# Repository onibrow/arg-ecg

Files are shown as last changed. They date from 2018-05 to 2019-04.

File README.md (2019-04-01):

# Arias Research Group - BLE ECG

## References

### BLE

Task - Use the nRF52 Development Kit to send ECG data from the ADAS1000 over BLE to a phone to record data.

After careful assesment, I've decided to move forward with the Arduino BLEPeripheral library, after finding that someone has ported the SoftDevice functionality to Arduino IDE. This was mainly due to my unfamiliarity with the BLE stack, and the daunting, semeingly unknown and unfriendly Nordic toolchain.

To get it to work, I had to install a few packages:

```
libstdc++5
lib32-libstdc++5
libudev0-shim
gperf
lib32-attr
lib32-libcap
lib32-libgpg-error
libg32-libgcrypt
lib32-system
lib32-libudev0-shim
```

[nRF5 board files](https://github.com/sandeepmistry/arduino-nRF5)

[Arduino BLEPeripheral](https://github.com/sandeepmistry/arduino-BLEPeripheral)

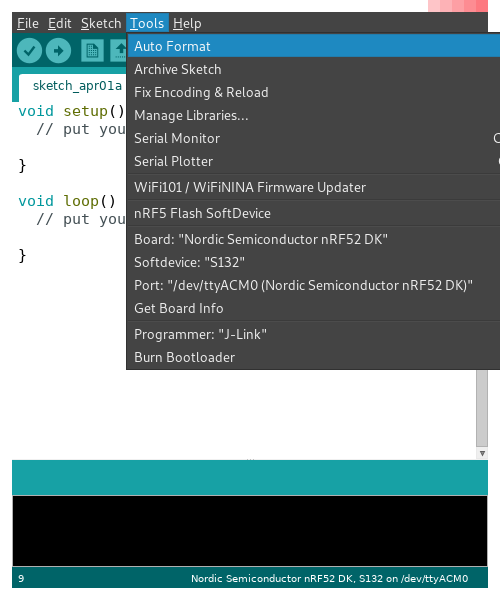
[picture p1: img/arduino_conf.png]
ard conf


### ADAS1000

[ADAS1000 Datasheet](https://www.analog.com/media/en/technical-documentation/data-sheets/ADAS1000_1000-1_1000-2.pdf)

[Eval Board Datasheet](http://www.analog.com/media/en/technical-documentation/user-guides/UG-426.pdf)

[Reference Design](https://www.analog.com/media/en/reference-design-documentation/reference-designs/CN0308.pdf)

There are two ADAS's on the eval board, one master one slave for a total of 12 electrode input. We'll utilize only 5 of them from the master chip using the pins LA, RA, LL, RLD, V1, V2. RLD (Right Leg Driver) can also be used as the common mode electrode. We can choose different electrode setups after we get the hardware to work by toggling what we want to use and get the optimal setup

SPI communication details

* Clock Polarity: Idle HIGH
* Clock Phase: Data is clocked into ADAS during the rising edges of SCLK, and shifted out (to be read) on falling edges of SCLK

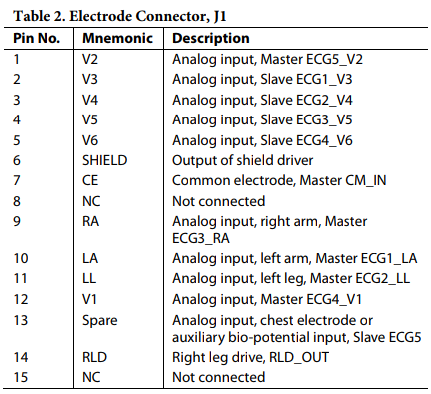
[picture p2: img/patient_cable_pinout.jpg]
patient


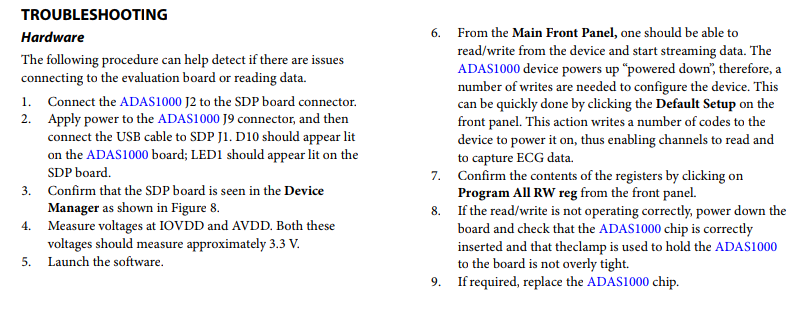
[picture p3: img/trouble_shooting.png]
trouble


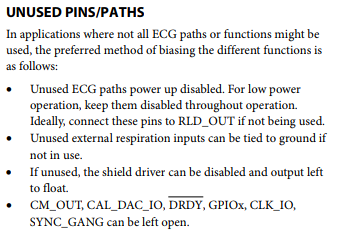
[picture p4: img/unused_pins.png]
unused


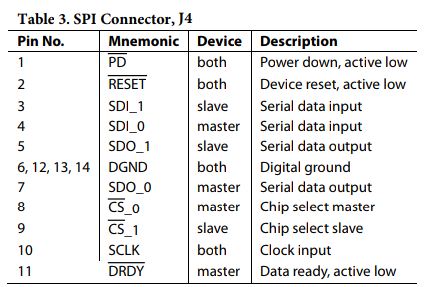
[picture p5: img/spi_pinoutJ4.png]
J4 SPI Out


[SPI Register Defs Page 60](https://www.analog.com/media/en/technical-documentation/data-sheets/ADAS1000_1000-1_1000-2.pdf)

### CC3200MOD\[DEPRACATED\] (WiFi)

[CC3200MOD Datasheet](http://www.ti.com/lit/ds/swrs166/swrs166.pdf)

[CC3200MOD LaunchPad User Guide](http://www.ti.com/lit/ug/swru397a/swru397a.pdf)

[CC3200MOD LaunchPad Schematic](http://www.ti.com/lit/df/tidrc48/tidrc48.pdf)

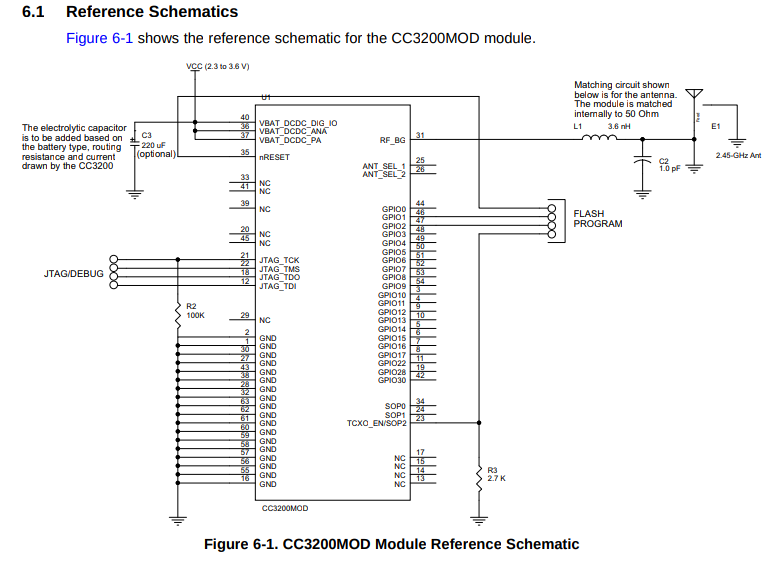
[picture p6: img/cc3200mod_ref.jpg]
CC3200MOD Refrence Schematic


[CC3200 Jumper Settings](http://energia.nu/guide/install/cc3200-guide/)

[CC3200 SPI <-> ADAS1000](https://ez.analog.com/linux-device-drivers/microcontroller-no-os-drivers/f/q-a/88100/adas-1000-to-arduino-code)

[More SPI stuff](https://www.element14.com/community/thread/46120/l/adas1000-interfacing-by-arduino-uno?displayFullThread=true)

## Other Wifi Modules

[ThingSpeak](https://thingspeak.com/)

[ESP8266](https://www.sparkfun.com/products/13678)

## IoT Server

Thinger.io is pretty nice - also has good integration with the launchpad - [Link](http://docs.thinger.io/arduino/#installation)

## Parts

All SMD components will be 0602 unless specified.

[8.192MHz](https://www.digikey.com/product-detail/en/citizen-finedevice-co-ltd/CM309S8.192MABJT/300-2039-1-ND/482155)

[1uH Inductor](https://www.digikey.com/product-detail/en/tdk-corporation/MLZ2012M1R0HT000/445-8657-1-ND/3077939)

[Chip Antenna](https://www.digikey.com/product-detail/en/taiyo-yuden/AH316M245001-T/587-2200-1-ND/2002898)

[DP3T](https://www.digikey.com/product-detail/en/c-k/JS203011JCQN/CKN10725CT-ND/6137639)

[2Pin JST](https://www.digikey.com/product-detail/en/jst-sales-america-inc/B2B-XH-A(LF)(SN)/455-2247-ND/1651045)

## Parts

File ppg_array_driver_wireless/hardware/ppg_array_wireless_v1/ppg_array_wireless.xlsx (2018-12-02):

Partli | st exported from C:/User | s/Yasser Khan/Dropbox/pr | oject_ppg_redundancy/ | ppg_array_driver_wireless/hardware/ppg_array_wireless_v1/ppg_array_wireless.sch at 10/5/2018 1:11 PM
Part | Value | Device | Package | Description PROD_ID
C1 | 1uF | CAP0603-CAP | 0603-CAP | Capacitor
C2 | 1uF | CAP0603-CAP | 0603-CAP | Capacitor
C3 | 18pF | CAP0603-CAP | 0603-CAP | Capacitor
C4 | 18pF | CAP0603-CAP | 0603-CAP | Capacitor
C5 | 2.2uF | CAP0603-CAP | 0603-CAP | Capacitor
C6 | 2.2uF | CAP0603-CAP | 0603-CAP | Capacitor
C7 | 1uF | CAP0603-CAP | 0603-CAP | Capacitor
C8 | 0.1uF | CAP0603-CAP | 0603-CAP | Capacitor
C9 | 1uF | CAP0603-CAP | 0603-CAP | Capacitor
C10 | 1uF | CAP0603-CAP | 0603-CAP | Capacitor
C11 | 1uF | CAP0603-CAP | 0603-CAP | Capacitor
C12 | 12pF | CAP0603-CAP | 0603-CAP | Capacitor
C13 | 12pF | CAP0603-CAP | 0603-CAP | Capacitor
C14 | 0.1uF | CAP0603-CAP | 0603-CAP | Capacitor
C15 | 0.1uF | CAP0603-CAP | 0603-CAP | Capacitor
C16 | 0.1uF | CAP0603-CAP | 0603-CAP | Capacitor
D1 | CZRU52C5V1 | CZRU52C5V1 | CZRU52C5V1
D2 | CZRU52C5V1 | CZRU52C5V1 | CZRU52C5V1
L1 | POWER | LEDCHIP-LED0603 | CHIP-LED0603 | LED
L2 | BLE | LEDCHIP-LED0603 | CHIP-LED0603 | LED
Q1 | ABRACON_ABM3_CRYSTAL | ABRACON_ABM3_CRYSTAL | ABRACON_ABM3_CRYSTAL
Q2 | FC-12M | FC-12M | FC-12M | kHz RANGE CRYSTAL UNIT
R1 | 1K | RESISTOR0603-RES | 0603-RES | Resistor
R2 | 1K | RESISTOR0603-RES | 0603-RES | Resistor
R3 | 10k | RESISTOR0603-RES | 0603-RES | Resistor
RESET |  | TAC_SWITCHSMD | TACTILE_SWITCH_SMD | SMD Tactiile Switch
S1 | AYZ0202 | AYZ0202 | AYZ0202 | SPDT Slide Switch SWCH-08179
U1 | MDBT40SMD | MDBT40SMD | MDBT40
U2 | AFE4490 | AFE4490 | QFN40-6X6
U3 | TESTING_ADXL335-PATRICK | TESTING_ADXL335-PATRICK | TESTING_LFCSP-16
U4 | ADG794 | ADG794 | QSOP16
U5 | MIC5211-LXYM6-TR | MIC5211-LXYM6-TR | SOT-23-6
X1 | 5034803200 | 5034803200 | 5034803200 | 0.5mm Pitch Connectors For FPC/FFC

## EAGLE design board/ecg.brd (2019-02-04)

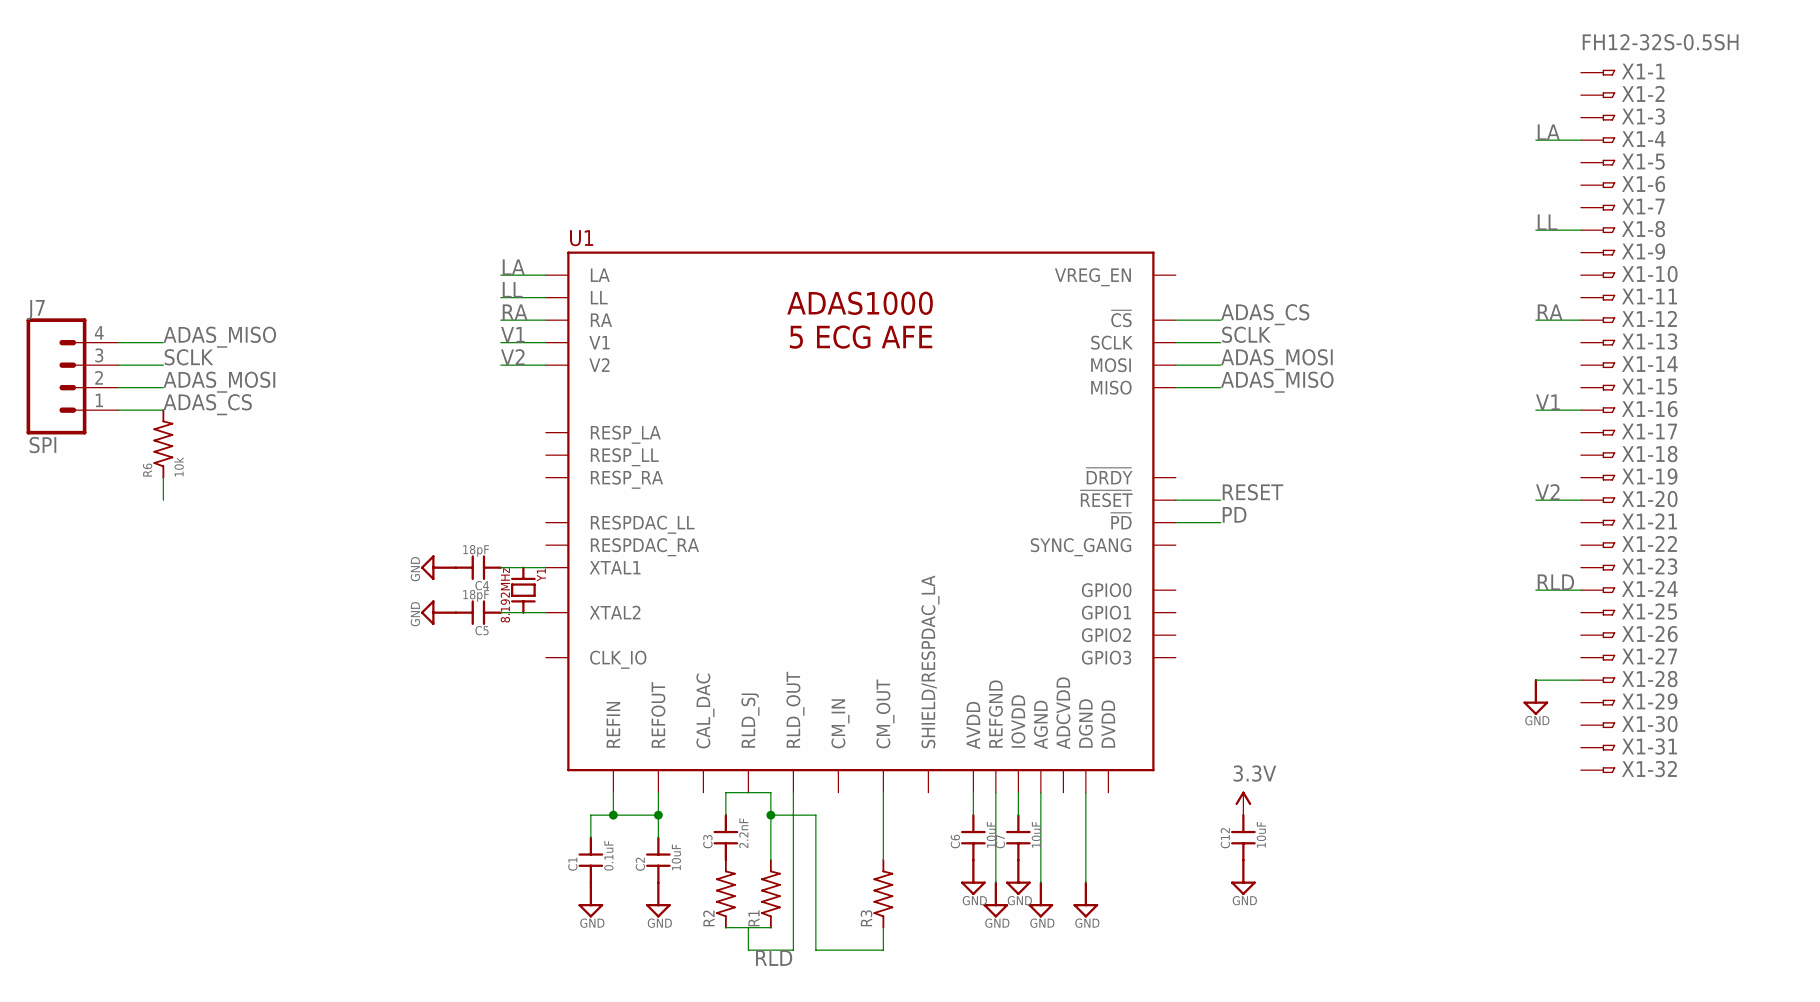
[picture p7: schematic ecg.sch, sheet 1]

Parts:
C1: 0.1uF; 0603-CAP
C2, C6, C7, C12: 10uF; 0603-CAP
C3: 2.2nF; 0603-CAP
C4, C5: 18pF; 0603-CAP
J7: SPI; 1X04
R1: 4M; R0603
R2: 100k; R0603
R3: 40k; R0603
R6: 10k; R0603
U1: ADAS1000; QFP50P1200X1200X160-65N
X1: FH12-32S-0.5SH
Y1: 8.192MHz; HC-49

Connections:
3.3V: C6.2, C7.2, C12.2, R6.1, U1.18 (AVDD), U1.23 (AVDD), U1.35 (IOVDD), U1.46 (IOVDD), U1.58 (AVDD), U1.63 (AVDD); also elsewhere on the board
ADAS_CS: J7.1, R6.2, U1.41 (!CS); also elsewhere on the board
ADAS_MISO: J7.4, U1.45 (MISO); also elsewhere on the board
ADAS_MOSI: J7.2, U1.43 (MOSI); also elsewhere on the board
GND: C1.1, C2.1, C4.2, C5.2, C6.1, C7.1, C12.1, U1.2 (AGND), U1.7 (REFGND), U1.15 (AGND), U1.24 (AGND), U1.25 (AGND), U1.31 (DGND), U1.34 (DGND), U1.40 (DGND), U1.47 (DGND), U1.50 (DGND), U1.56 (AGND), U1.57 (AGND), X1.28; also elsewhere on the board
LA: U1.10 (LA), X1.4
LL: U1.11 (LL), X1.8
unnamed: C1.2, C2.2, U1.8 (REFOUT), U1.9 (REFIN)
unnamed: C3.2, R1.2, R3.1, U1.21 (RLD_SJ)
unnamed: C3.1, R2.2
unnamed: R3.2, U1.22 (CM_OUT)
unnamed: C4.1, U1.27 (XTAL1), Y1.A
unnamed: C5.1, U1.28 (XTAL2), Y1.B
PD: U1.53 (!PD)
RA: U1.12 (RA), X1.12
RESET: U1.54 (!RESET)
RLD: R1.1, R2.1, U1.20 (RLD_OUT), X1.24
SCLK: J7.3, U1.44 (SCLK); also elsewhere on the board
V1: U1.13 (V1), X1.16
V2: U1.14 (V2), X1.20

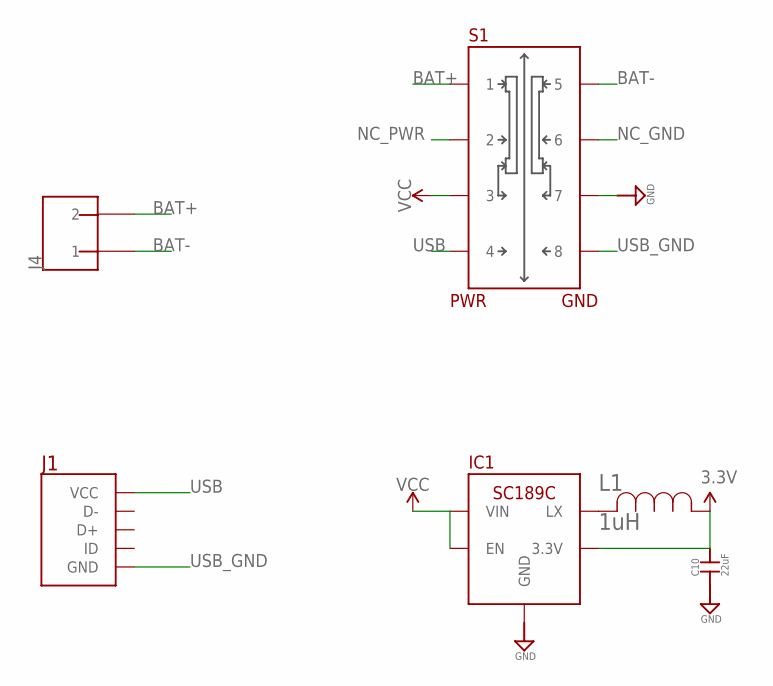
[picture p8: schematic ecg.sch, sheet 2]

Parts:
C10: 22uF; 0603-CAP
IC1: SC189C; SOT23-5
J1: USB_MICRO
J4: 2_PIN_JST-XH
L1: 1uH; IND_2012
S1: DP3T

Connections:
3.3V: C10.2, IC1.4 (3.3V), L1.1; also elsewhere on the board
BAT+: J4.P$2 (2), S1.1
BAT-: J4.P$1 (1), S1.5
GND: C10.1, IC1.2 (GND), S1.7; also elsewhere on the board
unnamed: IC1.5 (LX), L1.2
NC_GND: S1.6
NC_PWR: S1.2
USB: J1.VCC, S1.4
USB_GND: J1.GND, S1.8
VCC: IC1.1 (VIN), IC1.3 (EN), S1.3

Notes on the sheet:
PWR
GND

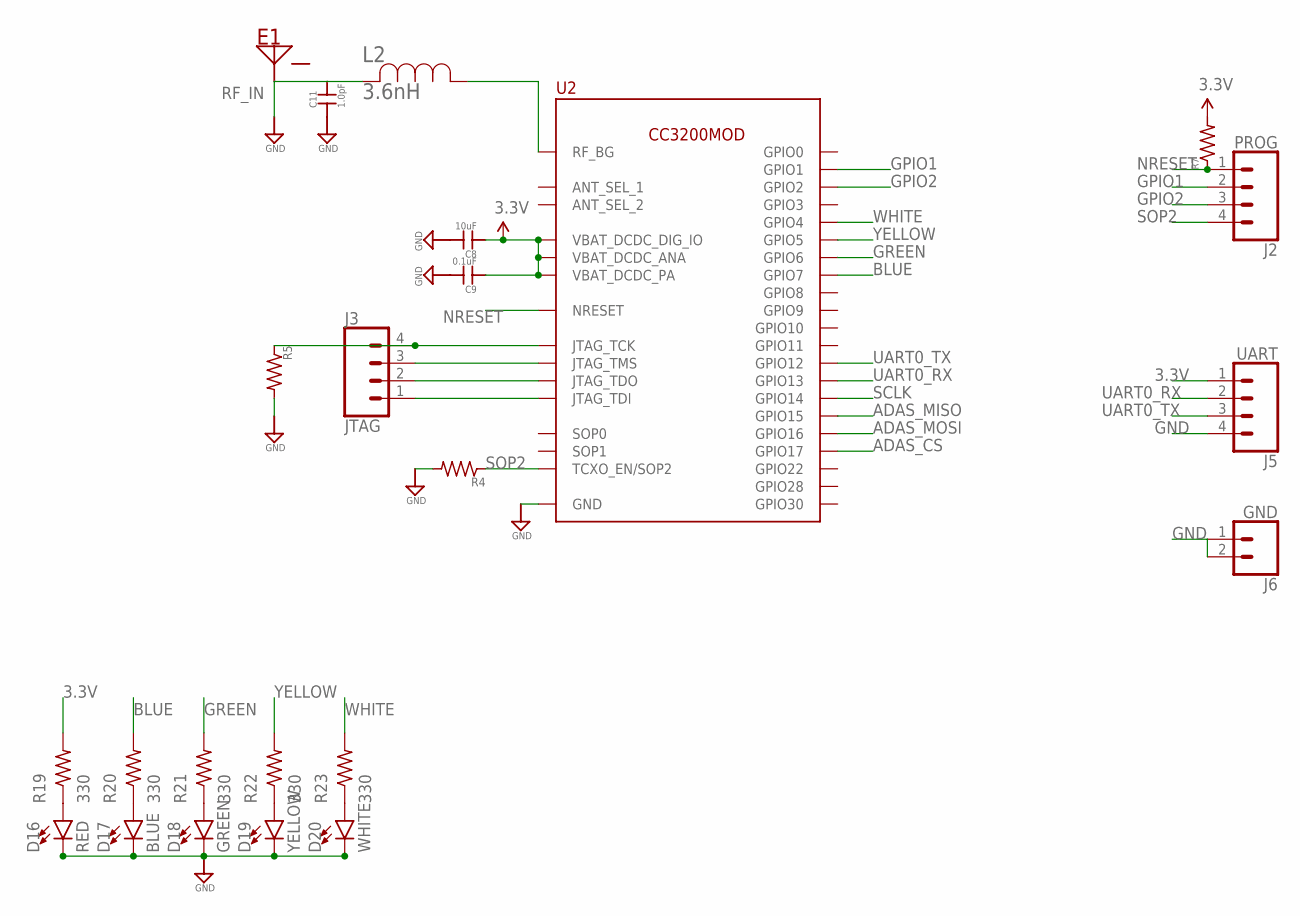
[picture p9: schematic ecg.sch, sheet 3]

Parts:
C8: 10uF; 0603-CAP
C9: 0.1uF; 0603-CAP
C11: 1.0pF; 0603-CAP
D16: RED; LED-0603
D17: BLUE; LED-0603
D18: GREEN; LED-0603
D19: YELLOW; LED-0603
D20: WHITE; LED-0603
E1: AH316M245001-T; CHIP_ANT
J2: PROG; 1X04
J3: JTAG; 1X04
J5: UART; 1X04
J6: GND; 1X02
L2: 3.6nH; IND0402_22N_TAI
R4: 2.7k; R0603
R5: 100k; R0603
R7: R-US_R0603; R0603
R19, R20, R21, R22, R23: 330; R0402
U2: CC3200MOD; 63-SMD

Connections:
3.3V: C8.1, C9.1, J5.1, R7.2, R19.2, U2.P$36 (VBAT_DCDC_ANA), U2.P$37 (VBAT_DCDC_PA), U2.P$40 (VBAT_DCDC_DIG_IO); also elsewhere on the board
ADAS_CS: U2.P$8 (GPIO17); also elsewhere on the board
ADAS_MISO: U2.P$6 (GPIO15); also elsewhere on the board
ADAS_MOSI: U2.P$7 (GPIO16); also elsewhere on the board
BLUE: R20.2, U2.P$52 (GPIO7)
GND: C8.2, C9.2, C11.1, D16.C, D17.C, D18.C, D19.C, D20.C, J5.4, J6.1, J6.2, R4.2, R5.2, U2.P$1 (GND), U2.P$2 (GND), U2.P$16 (GND), U2.P$27 (GND), U2.P$28 (GND), U2.P$30 (GND), U2.P$32 (GND), U2.P$38 (GND), U2.P$43 (GND), U2.P$55 (GND), U2.P$56 (GND), U2.P$57 (GND), U2.P$58 (GND), U2.P$59 (GND), U2.P$60 (GND), U2.P$61 (GND), U2.P$62 (GND), U2.P$63 (GND); also elsewhere on the board
GPIO1: J2.2, U2.P$46 (GPIO1)
GPIO2: J2.3, U2.P$47 (GPIO2)
GREEN: R21.2, U2.P$51 (GPIO6)
unnamed: J3.4, R5.1, U2.P$21 (JTAG_TCK)
unnamed: J3.3, U2.P$22 (JTAG_TMS)
unnamed: J3.2, U2.P$18 (JTAG_TDO)
unnamed: J3.1, U2.P$12 (JTAG_TDI)
unnamed: D16.A, R19.1
unnamed: D17.A, R20.1
unnamed: D18.A, R21.1
unnamed: D19.A, R22.1
unnamed: D20.A, R23.1
NRESET: J2.1, R7.1, U2.P$35 (NRESET)
RF_BG: L2.1, U2.P$31 (RF_BG)
RF_IN: C11.2, E1.INPUT, L2.2
SCLK: U2.P$5 (GPIO14); also elsewhere on the board
SOP2: J2.4, R4.1, U2.P$23 (TCXO_EN/SOP2)
UART0_RX: J5.2, U2.P$10 (GPIO13)
UART0_TX: J5.3, U2.P$9 (GPIO12)
WHITE: R23.2, U2.P$49 (GPIO4)
YELLOW: R22.2, U2.P$50 (GPIO5)

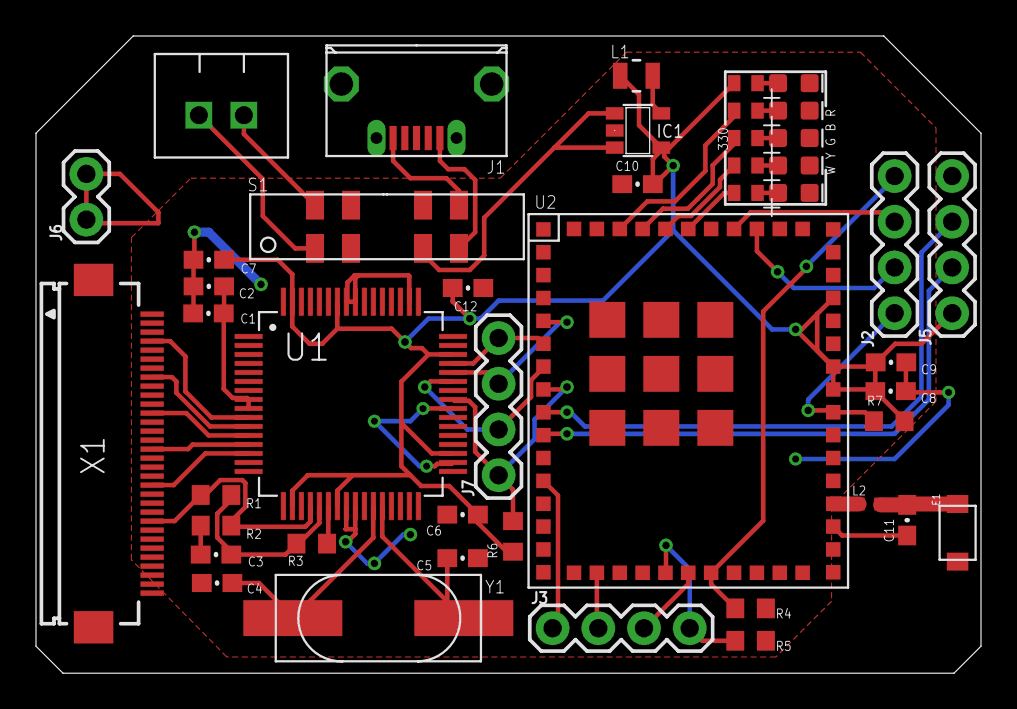
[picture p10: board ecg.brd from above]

Board: 2 copper layers, 52.5 x 35.4 mm, 45 parts (0 on the bottom side), 45 nets.

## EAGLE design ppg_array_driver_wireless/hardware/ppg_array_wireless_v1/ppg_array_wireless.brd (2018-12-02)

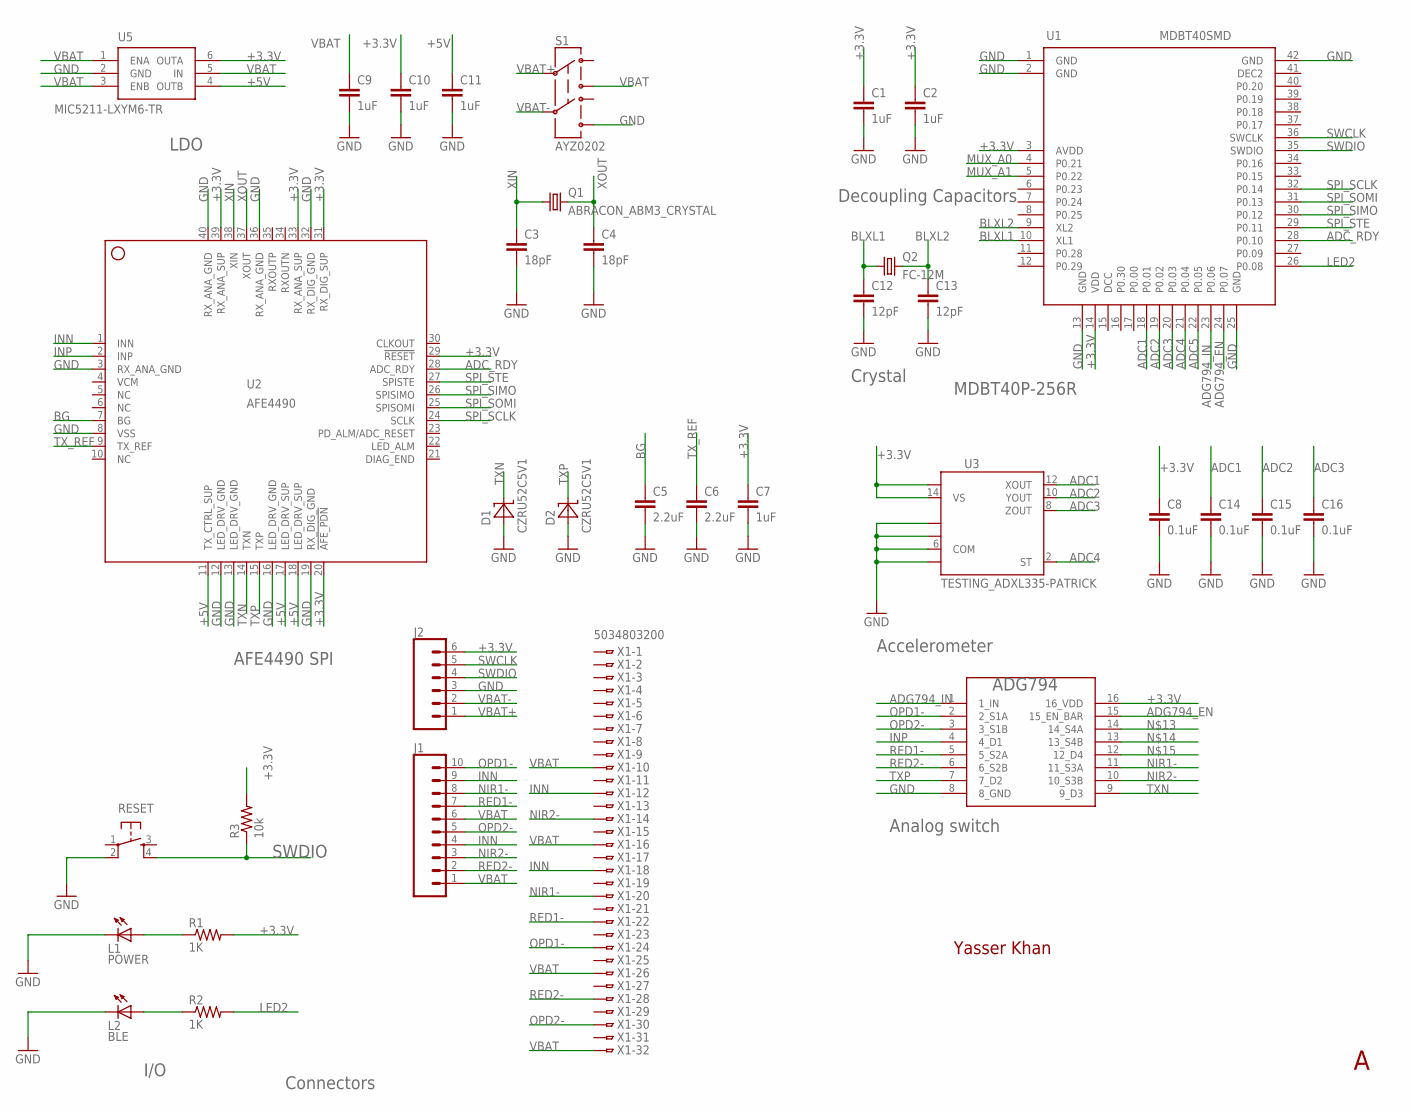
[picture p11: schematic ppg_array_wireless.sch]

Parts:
C1, C2, C7, C9, C10, C11: 1uF; 0603-CAP
C3, C4: 18pF; 0603-CAP
C5, C6: 2.2uF; 0603-CAP
C8, C14, C15, C16: 0.1uF; 0603-CAP
C12, C13: 12pF; 0603-CAP
D1, D2: CZRU52C5V1
J1: CONN_10"; 1X10
J2: CONN_06SILK_FEMALE_PTH; 1X06
L1: POWER; CHIP-LED0603
L2: BLE; CHIP-LED0603
Q1: ABRACON_ABM3_CRYSTAL
Q2: FC-12M
R1, R2: 1K; 0603-RES
R3: 10k; 0603-RES
RESET: TAC_SWITCHSMD; TACTILE_SWITCH_SMD
S1: AYZ0202
U1: MDBT40SMD; MDBT40
U2: AFE4490; QFN40-6X6
U3: TESTING_ADXL335-PATRICK; TESTING_LFCSP-16
U4: ADG794; QSOP16
U5: MIC5211-LXYM6-TR; SOT-23-6
X1: 5034803200

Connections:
+3.3V: C1.1, C2.1, C7.1, C8.1, C10.1, J2.6, R1.2, R3.2, U1.3 (AVDD), U1.14 (VDD), U2.20 (!AFE_PDN), U2.29 (!RESET), U2.31 (RX_DIG_SUP), U2.33 (RX_ANA_SUP), U2.39 (RX_ANA_SUP), U3.14 (VS), U3.15 (VS), U4.16 (16_VDD), U5.6 (OUTA)
+5V: C11.1, U2.11 (TX_CTRL_SUP), U2.17 (LED_DRV_SUP), U2.18 (LED_DRV_SUP), U5.4 (OUTB)
ADC1: C14.1, U1.18 (P0.01), U3.12 (XOUT)
ADC2: C15.1, U1.19 (P0.02), U3.10 (YOUT)
ADC3: C16.1, U1.20 (P0.03), U3.8 (ZOUT)
ADC4: U1.21 (P0.04), U3.2 (ST)
ADC5: U1.22 (P0.05)
ADC_RDY: U1.28 (P0.10), U2.28 (ADC_RDY)
ADG794_EN: U1.24 (P0.07), U4.15 (15_EN_BAR)
ADG794_IN: U1.23 (P0.06), U4.1 (1_IN)
BG: C5.1, U2.7 (BG)
BLXL1: C12.1, Q2.1, U1.10 (XL1)
BLXL2: C13.1, Q2.2, U1.9 (XL2)
GND: C1.2, C2.2, C3.2, C4.2, C5.2, C6.2, C7.2, C8.2, C9.2, C10.2, C11.2, C12.2, C13.2, C14.2, C15.2, C16.2, D1.A, D2.A, J2.3, L1.C, L2.C, RESET.2, S1.4 (6), U1.1 (GND), U1.2 (GND), U1.13 (GND), U1.25 (GND), U1.42 (GND), U2.3 (RX_ANA_GND), U2.8 (VSS), U2.12 (LED_DRV_GND), U2.13 (LED_DRV_GND), U2.16 (LED_DRV_GND), U2.19 (RX_DIG_GND), U2.32 (RX_DIG_GND), U2.36 (RX_ANA_GND), U2.40 (RX_ANA_GND), U2.EXP@1 (GND), U2.EXP@2 (GND), U2.EXP@3 (GND), U2.EXP@4 (GND), U2.EXP@5 (GND), U2.EXP@6 (GND), U2.EXP@7 (GND), U2.EXP@8 (GND), U2.EXP@9 (GND), U2.EXP@10 (GND), U2.EXP@11 (GND), U2.EXP@12 (GND), U2.EXP@13 (GND), U2.EXP@14 (GND), U2.EXP@15 (GND), U2.EXP@16 (GND), U2.PWR@1 (GND), U2.PWR@2 (GND), U3.3 (COM), U3.5 (COM), U3.6 (COM), U3.7 (COM), U4.8 (8_GND), U5.2 (GND)
INN: J1.4, J1.9, U2.1 (INN), X1.12, X1.18
INP: U2.2 (INP), U4.4 (4_D1)
LED2: R2.2, U1.26 (P0.08)
MUX_A0: U1.4 (P0.21)
MUX_A1: U1.5 (P0.22)
unnamed: L1.A, R1.1
unnamed: L2.A, R2.1
NIR1-: J1.8, U4.11 (11_S3A), X1.20
NIR2-: J1.3, U4.10 (10_S3B), X1.14
OPD1-: J1.10, U4.2 (2_S1A), X1.24
OPD2-: J1.5, U4.3 (3_S1B), X1.30
RED1-: J1.7, U4.5 (5_S2A), X1.22
RED2-: J1.2, U4.6 (6_S2B), X1.28
SPI_SCLK: U1.32 (P0.14), U2.24 (SCLK)
SPI_SIMO: U1.30 (P0.12), U2.26 (SPISIMO)
SPI_SOMI: U1.31 (P0.13), U2.25 (SPISOMI)
SPI_STE: U1.29 (P0.11), U2.27 (SPISTE)
SWCLK: J2.5, U1.36 (SWCLK)
SWDIO: J2.4, R3.1, RESET.4, U1.35 (SWDIO)
TXN: D1.C, U2.14 (TXN), U4.9 (9_D3)
TXP: D2.C, U2.15 (TXP), U4.7 (7_D2)
TX_REF: C6.1, U2.9 (TX_REF)
VBAT: C9.1, J1.1, J1.6, S1.1 (3), U5.1 (ENA), U5.3 (ENB), U5.5 (IN), X1.10, X1.16, X1.26, X1.32
VBAT+: J2.1, S1.2
VBAT-: J2.2, S1.5
XIN: C3.1, Q1.P$1 (1), U2.38 (XIN)
XOUT: C4.1, Q1.P$2 (2), U2.37 (XOUT)

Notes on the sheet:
LDO
AFE4490 SPI
I/O
Connectors
MDBT40P-256R
Yasser Khan
Crystal
Decoupling Capacitors
Accelerometer
Analog switch

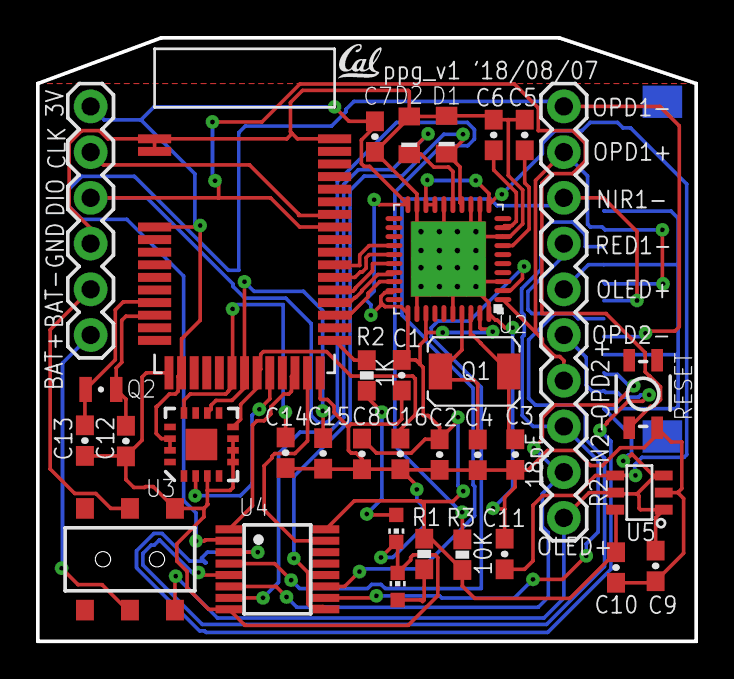
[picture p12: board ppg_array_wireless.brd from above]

Board: 2 copper layers, 36.6 x 33.5 mm, 36 parts (1 on the bottom side), 38 nets.

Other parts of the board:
U$1: CAL

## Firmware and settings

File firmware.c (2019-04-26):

#include "nrf_drv_spi.h"
#include "app_util_platform.h"
#include "nrf_gpio.h"
#include "nrf_delay.h"
#include "boards.h"
#include "app_error.h"
#include <string.h>
#include "nrf_log.h"
#include "nrf_log_ctrl.h"
#include "nrf_log_default_backends.h"

// ADAS 1000 Register Addresses
const char NOP       = 0x00;   // No Operation Register
const char ECGCTL    = 0x01;   // ECG control - reset value 0x000000
const char FRMCTL    = 0x0A;   // Controls what shows up in FRAME
const char LOFFCTL   = 0x02;   // Lead-off control 
const char PACEAMPTH = 0x07;   // Show PACEAMPTH or Pace amplitude threshold // reset value 0x242424
const char LADATA    = 0x11;   // LA or Lead I data 
const char LLDATA    = 0x12;   // LL or Lead II data
const char RADATA    = 0x13;   // RA or Lead III data
const char V1DATA    = 0x14;   // V1 or V1’ data
const char V2DATA    = 0x15;   // V2 or V2’ data
const char PACEDATA  = 0x1A;   // Read pace detection data/status
const char FRAMES    = 0x40;   // Frame header - reset value 0x800000

// ADAS 1000 ECG Control Register Details
char ECG_EN    = 0x1F;   // Enables LA, LL, RA, V1, V2 Channels (1 = Enable) (5 Bit)
char CHCONFIG  = 0x00;   // 0 = Single Ended Input; 1 = Differential Input
char GAIN      = 0x00;   // Overall gain - 00 = x1.4; 01 = x2.1; 10 = x2.8; 11 = x4.2 (user cal req)
char VREFBUF   = 0x00;   // VREF buffer enable
char CLKEXT    = 0x00;   // External Clock is Used (0 = XTAL; 1 = Internal)
char MASTER    = 0x01;   // Determines Master or Slave in Gang Mode (0 = Slave; 1 = Master)
char GANG      = 0x00;   // Enables Gang Mode (0 = single; 1 = gang) 
char HP        = 0x01;   // High Power / Noise Setting (0 = Low Power; 1 = Low Noise)
char CNVEN     = 0x01;   // Enables ADC conversion and filters
char PWREN     = 0x01;   // Enables Power

// ADAS 1000 Frame Control Register Details (0 = included; 1 = excluded)
char ECG_CHN   = 0x00;   // LA, LL, RA, V1, V2 (5 Bit)
char PACEDIS   = 0x01;   // Pace Detection
char RESPMDIS  = 0x01;   // Respiration Magnitude
char RESPPHDIS = 0x01;   // Respiration Phase
char LOFFDIS   = 0x01;   // Lead Off Status
char GPIODIS   = 0x01;   // GPIO Word
char CRCDIS    = 0x00;   // CRC Word
char ADIS      = 0x00;   // Autodisable PACEDIS, RESPMDIS, LOFFDIS if flags are not set
char RDYRPT    = 0x00;   // Indicates DATA READY
char DATAFMT   = 0x00;   // 0 = Digital Lead/Vector Format; 1 = Electrode Format
char SKIP      = 0x00;   // 00 = output every frame; 01 = output every other frame; 1x = output every 4th frame
char FRMRATE   = 0x00;   // 00 = 2kHz; 01 = 16kHz, 10 = 128 kHz, 11 = 31.25 Hz

#define SPI_INSTANCE  0           /**< SPI instance index. */
static const nrf_drv_spi_t spi = NRF_DRV_SPI_INSTANCE(SPI_INSTANCE);  /**< SPI instance. */
static volatile bool spi_xfer_done;  /**< Flag used to indicate that SPI instance completed the transfer. */

uint8_t       m_tx_buf[4];                        /**< TX buffer. */
uint8_t       m_rx_buf[4];                        /**< RX buffer. */
static const uint8_t m_length = sizeof(m_tx_buf); /**< Transfer length. */

/**
 * @brief SPI user event handler.
 * @param event
 */
void spi_event_handler(nrf_drv_spi_evt_t const * p_event,
                       void *                    p_context)
{
    spi_xfer_done = true;
    NRF_LOG_INFO("Transfer completed.");
    if (m_rx_buf[0] != 0)
    {
        NRF_LOG_INFO(" Received:");
        NRF_LOG_HEXDUMP_INFO(m_rx_buf, strlen((const char *)m_rx_buf));
    }
}

/**
 * @brief A NOP read to delay a SPI cycle
 * @param spi - SPI instance
 */

void ADAS_1000_read_noop(nrf_drv_spi_t const * const spi) {
  nrf_delay_us(50);
  APP_ERROR_CHECK(nrf_drv_spi_transfer(spi, 0x00000000, m_length, m_rx_buf, m_length));
  printf("0x");
  for (int i = 0; i < 4; i++) {
    printf("%02x", (unsigned char) m_rx_buf[i]);
  }
  printf("\n");
  return;
}

/**
 * @brief Reads out a register value on ADAS1000 - FOR DEBUGGING
 * @param spi - SPI instance
 * @param reg - Register to read
 */
void ADAS_1000_read_reg(nrf_drv_spi_t const * const spi, char reg) {
  /* R/W:  [31]
     Reg:  [30:24]
     Data: [23:0] */
  int payload = (0b0 << 31) | (reg << 24) | 0x000000;
  printf("Reading Reg 0x%02x: ", reg);
  for (int i = 0; i < 4; i++) {
    m_tx_buf[i] = (payload >> (24 - (8 * i))) & 0xFF;
  }
  APP_ERROR_CHECK(nrf_drv_spi_transfer(spi, m_tx_buf, m_length, m_rx_buf, m_length));
  ADAS_1000_read_noop(spi);
  printf("0x");
  for (int i = 0; i < 4; i++) {
    printf("%02x", (unsigned char) m_rx_buf[i]);
  }
  printf("\n");
  return;
}

/**
 * @brief Reads out a register value on ADAS1000
 * @param spi   - SPI instance
 * @param reg   - Register to write
 * @param value - Value to write
 */
void ADAS_1000_write_reg(nrf_drv_spi_t const * const spi, char reg, int value) {
  /* R/W:  [31]
     Reg:  [30:24]
     Data: [23:0] */
  int payload = (0b1 << 31) | (reg << 24) | (value & 0x00FFFFFF);
//  printf("Writing: 0x%02x to Reg 0x%02x ", (unsigned int) value, (unsigned char) reg);
  for (int i = 0; i < 4; i++) {
    m_tx_buf[i] = (payload >> (24 - (8 * i))) & 0xFF;
//    printf("%02x", (unsigned char) m_tx_buf[i]);
  }
  printf("\n");
  APP_ERROR_CHECK(nrf_drv_spi_transfer(spi, m_tx_buf, m_length, m_rx_buf, m_length));
  return;
}


/**
 * @brief Configures the ECG Control Register
 * @param spi - SPI instance
 */
void ADAS_1000_ecgctl_setup(nrf_drv_spi_t const * const spi) {
  int ecg_ctl = 0x00000000 | ECG_EN << 19 | CHCONFIG << 10 | GAIN << 8 | VREFBUF << 7 | 
                CLKEXT << 6 | MASTER << 5 | GANG << 4 | HP << 3 | CNVEN << 2 | PWREN << 1;
  ADAS_1000_write_reg(spi, ECGCTL, ecg_ctl);
  return;
}

/**
 * @brief Configures the Frame Control Register
 * @param spi - SPI instance
 */
void ADAS_1000_frmctl_setup(nrf_drv_spi_t const * const spi) {
  int frm_ctl = 0x00078000 | ECG_CHN << 19 | PACEDIS << 14 | RESPMDIS << 13 | RESPPHDIS << 12 | LOFFDIS << 11 | 
                GPIODIS << 10 | CRCDIS << 9 | ADIS << 7 | RDYRPT << 6 | DATAFMT << 4 | SKIP << 2 | FRMRATE;
  ADAS_1000_write_reg(spi, FRMCTL, frm_ctl);
  return;
}

/**
 * @brief Reads out an entire Frame from the ADAS1000
 * @param spi - SPI instance
 */
void ADAS_1000_frame_readout(nrf_drv_spi_t const * const spi, uint8_t frm_len) {
  return;
}

int main(void)
{
    bsp_board_init(BSP_INIT_LEDS);

    APP_ERROR_CHECK(NRF_LOG_INIT(NULL));
    NRF_LOG_DEFAULT_BACKENDS_INIT();

    nrf_drv_spi_config_t spi_config = NRF_DRV_SPI_DEFAULT_CONFIG;
    spi_config.ss_pin    = SPI_SS_PIN;
    spi_config.miso_pin  = SPI_MISO_PIN;
    spi_config.mosi_pin  = SPI_MOSI_PIN;
    spi_config.sck_pin   = SPI_SCK_PIN;
    spi_config.mode      = NRF_DRV_SPI_MODE_3;
    spi_config.frequency = NRF_DRV_SPI_FREQ_8M

    APP_ERROR_CHECK(nrf_drv_spi_init(&spi, &spi_config, spi_event_handler, NULL));

    printf("\n---Setting up Frame Control---\n");
    ADAS_1000_frmctl_setup(&spi);
    ADAS_1000_read_reg(&spi, FRMCTL);

    printf("\n---Setting up ECG Control---\n");
    ADAS_1000_ecgctl_setup(&spi);
    ADAS_1000_read_reg(&spi, ECGCTL);

    printf("\n---Setting up Lead Off Control---\n");
    ADAS_1000_write_reg(&spi, LOFFCTL, 0x000000);
    ADAS_1000_read_reg(&spi, LOFFCTL);
    
    // Start Frame Readout
    printf("\n---Starting Frame Acquisition\n");
    ADAS_1000_read_reg(&spi, FRAMES);
    while (1)
    {
        // Reset rx buffer and transfer done flag
        memset(m_rx_buf, 0, m_length);
        spi_xfer_done = false;
        ADAS_1000_read_noop(&spi);
        while (!spi_xfer_done)
        {
            __WFE();
        }

        NRF_LOG_FLUSH();

        bsp_board_led_invert(BSP_BOARD_LED_0);
        nrf_delay_ms(500);
    }
}

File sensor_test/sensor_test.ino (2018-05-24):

/*
  WiFi Web Server LED Blink
  And Sensor Testing
 */
#ifndef __CC3200R1M1RGC__
#include <SPI.h>
#endif
#include <WiFi.h>
#include "Adafruit_TMP006.h"

Adafruit_TMP006 tmp006(0x41);
int temp;

// your network name also called SSID
char ssid[] = "seiya-wifi";
// your network password
char password[] = "seiyaono";
// your network key Index number (needed only for WEP)
int keyIndex = 0;

WiFiServer server(80);

void setup() {
  Serial.begin(115200);      // initialize serial communication

  // Initialize temperature Sensor
   if (! tmp006.begin()) 
  {
    Serial.println("No sensor found");
  }
  else
  {
    Serial.print("Temperature Sensor Initialized\n");
  }

  pinMode(RED_LED, OUTPUT);      // set the LED pin mode

  // attempt to connect to Wifi network:
  Serial.print("Attempting to connect to Network named: ");
  // print the network name (SSID);
  Serial.println(ssid); 
  // Connect to WPA/WPA2 network. Change this line if using open or WEP network:
  WiFi.begin(ssid, password);
  while ( WiFi.status() != WL_CONNECTED) {
    // print dots while we wait to connect
    Serial.print(".");
    delay(300);
  }
  
  Serial.println("\nYou're connected to the network");
  Serial.println("Waiting for an ip address");
  
  while (WiFi.localIP() == INADDR_NONE) {
    // print dots while we wait for an ip addresss
    Serial.print(".");
    delay(300);
  }

  Serial.println("\nIP Address obtained");
  
  // you're connected now, so print out the status  
  printWifiStatus();

  Serial.println("Starting webserver on port 80");
  server.begin();                           // start the web server on port 80
  Serial.println("Webserver started!");
}

void loop() {
  int i = 0;
  WiFiClient client = server.available();   // listen for incoming clients
  tmp006.wake();
  temp = tmp006.readDieTempC();
  
  if (client) {                             // if you get a client,
    Serial.println("new client");           // print a message out the serial port
    char buffer[150] = {0};                 // make a buffer to hold incoming data
    while (client.connected()) {            // loop while the client's connected
      if (client.available()) {             // if there's bytes to read from the client,
        char c = client.read();             // read a byte, then
        Serial.write(c);                    // print it out the serial monitor
        if (c == '\n') {                    // if the byte is a newline character

          // if the current line is blank, you got two newline characters in a row.
          // that's the end of the client HTTP request, so send a response:
          if (strlen(buffer) == 0) {
            // HTTP headers always start with a response code (e.g. HTTP/1.1 200 OK)
            // and a content-type so the client knows what's coming, then a blank line:
            client.println("HTTP/1.1 200 OK");
            client.println("Content-type:text/html");
            client.println();

            // the content of the HTTP response follows the header:
            client.println("CC3200 Board Active");
            client.print("Temperature: ");
            client.println(temp);

            // The HTTP response ends with another blank line:
            client.println();
            // break out of the while loop:
            break;
          }
          else {      // if you got a newline, then clear the buffer:
            memset(buffer, 0, 150);
            i = 0;
          }
        }
        else if (c != '\r') {    // if you got anything else but a carriage return character,
          buffer[i++] = c;      // add it to the end of the currentLine
        }
        // Heartbeat
        digitalWrite(RED_LED, HIGH);
      }
    }
    // close the connection:
    client.stop();
    Serial.println("client disonnected");
    digitalWrite(RED_LED, LOW);
  }
}

//
//a way to check if one array ends with another array
//
boolean endsWith(char* inString, char* compString) {
  int compLength = strlen(compString);
  int strLength = strlen(inString);
  
  //compare the last "compLength" values of the inString
  int i;
  for (i = 0; i < compLength; i++) {
    char a = inString[(strLength - 1) - i];
    char b = compString[(compLength - 1) - i];
    if (a != b) {
      return false;
    }
  }
  return true;
}

void printWifiStatus() {
  // print the SSID of the network you're attached to:
  Serial.print("SSID: ");
  Serial.println(WiFi.SSID());

  // print your WiFi IP address:
  IPAddress ip = WiFi.localIP();
  Serial.print("IP Address: ");
  Serial.println(ip);

  // print the received signal strength:
  long rssi = WiFi.RSSI();
  Serial.print("signal strength (RSSI):");
  Serial.print(rssi);
  Serial.println(" dBm");
  // print where to go in a browser:
  Serial.print("To see this page in action, open a browser to http://");
  Serial.println(ip);
}

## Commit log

2018-05-23 add sensor test ino file
2018-11-25 start layout
    [ecg.sch]
2018-11-25 do some power work
    [ecg.sch]
2018-11-26 do tons of library work and nearly wrap up schematic
    [ecg.brd, ecg.sch]
2018-12-02 add yassers ble
    [ppg_array_wireless.brd, ppg_array_wireless.sch, ppg_array_wireless.xlsx]
2018-12-02 make progress with the board
    [ecg.brd, ecg.sch]
2018-12-06 finish bom and replace 0402
    [ecg.brd, ecg.sch]
2018-12-06 make sure the pinouts are same as te board
    [ecg.brd, ecg.sch]
2019-01-23 fix antenna
    [ecg.brd, ecg.sch]
2019-01-29 fix cs pin and add more links
    [ecg.brd, ecg.sch]
2019-01-30 add spi pinout from adas1000 eval
2019-01-30 add more spi links
2019-01-30 small changes
    [ecg.brd]
2019-02-04 make sure pullup for !CS
    [ecg.brd, ecg.sch]
2019-02-04 start spi test
2019-03-31 add nrf sdk
    [config.txt]
2019-04-01 remove sdk
    [config.txt]
2019-04-26 add print for frame

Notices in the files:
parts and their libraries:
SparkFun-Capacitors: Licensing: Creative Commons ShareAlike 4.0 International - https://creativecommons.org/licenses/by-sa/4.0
